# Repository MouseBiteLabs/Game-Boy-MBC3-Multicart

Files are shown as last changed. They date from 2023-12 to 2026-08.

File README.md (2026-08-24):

# Game Boy MBC3 Multicart

This is my design of a flashable MBC3-based multicart for the Game Boy. You can make a 2-in-1 or 4-in-1 cartridge, that changes games based on a button press or power cycling the Game Boy. With this board you can also make a single game, but with the addition of a pressable reset button on the cartridge.

The features are as follows:

- Able to make a cartridge with either 2x 2 MB games or 4x 1 MB games
- Adds a pressable button to the cartridge (no shell cutting required)
  - The button can be configured to cycle games on the cart, reset the console, or both
- Configurable to have separate save data for each game, or to share the same save data across multiple games
- Fully compatible with the <a href="https://www.gbxcart.com/">GBxCart RW</a> so you can transfer games and save files to and from the board

Some examples of fun cartridges you can make with this board are:
- A single Pokemon game that has a reset button
- Both Pokemon Gold and Silver with separate saves
- Both Pokemon Gold and Silver with *the same* save (save files are compatible between versions!)
- Both Pokemon Gold and Silver with *the same* save that can switch between versions *during gameplay without resetting* (hotswap!)
- A single copy of Mary-Kate and Ashley - Pocket Planner with two separate save files

assemblepic

boardscan

All gerbers and source files can be found in this repo, as this project is fully open source. Technical documentation of the board can be found in the Technical folder.

## Tutorial Video

Here's a video companion to this repository, but you will still need to read the repo to complete the build.

Multicart Video Tutorial (http://www.youtube.com/watch?v=DJ7rJUZhDuM "Game Boy Multicart Tutorial (Pokemon Gold and Silver)")

## Important Things Before You Start

The most important thing to note is that SW2A MUST be in the OFF position. The board is still fully functional as long as you rely on the button inside the cartridge to switch games. **You cannot cycle games by turning the power on and off.** Details are below.

1) To use this board, you need to have an original Game Boy game that uses an MBC3 mapper chip. <a href="https://catskull.net/gb-rom-database/">You can find a list of games and their mappers here</a>. Use the search function. Please note the RAM is in bytes, not bits. Since SRAM in this repo is defined in bits, you need to convert by multiplying the number of bytes by 8.
2) You will need to remove the MBC3 from your donor cartridge for use on this board. This will require a hot air rework station or a hot plate. There's a list below of other parts you can re-use from the donor cartridge.
3) When soldering parts on, it's a good idea to put kapton tape or otherwise cover the bottom cartridge edge. You do not want to get solder on the cartridge contacts.
4) I am not responsible for any damage you do to your self or your property. Attempt this project at your own risk.
5) I do not guarantee design compatibility. You may encounter issues with certain games. There is also a chance I have made an error in the design or the BOM - if this is the case, I will do everything I can to address the problem as quickly as possible.
6) If you are using this board to make games other than for personal use, you must have permission from the originator to use and distribute any ROM images or other related material. You are responsible for making sure you adhere to any license requirements.

DO NOT use my circuit boards for profiting from stolen work - this especially includes homebrew content, ROM hacks, and using fan-made labels without permission from the originator. **Support original creators!**

## Board Characteristics and Order Information

The zipped folder contains all the gerber files for this board. The following options **must** be chosen when ordering boards for yourself.

- Thickness: 0.8mm
- Surface Finish: ENIG
- Gold Fingers: Yes, 30° chamfer

**Add this note to orders:** "The milling.gbr layer indicates where an unplated slot should be added to the board. Please add an unplated slot as indicated."

You can use the zipped folder at any board fabricator you like. You may also buy the board from PCBWay using this link (disclosure: I receive 10% of the sale value to go twoards future PCB orders of my own):

<a href="https://www.pcbway.com/project/shareproject/Game_Boy_MBC3_Multicart_9962e82f.html">PCB from PCBWay</a>

<a href="https://oshpark.com/shared_projects/9DCMXwOu">The board is also listed on OSH Park as well.</a> **Be sure to get them in 0.8mm thickness if you order from here.**

### Purchase from My Website

You can purchase this circuit board at my website, [https://mousebitelabs.store](https://mousebitelabs.store). Click the following image to be directed to the specific item listing:

<a href="https://mousebitelabs.store/products/game-boy-mbc3-multicart-circuit-board">PCB from MouseBiteLabs</a>

### Purchase from Etsy

I also offer the board on Etsy, if you would rather purchase through there - click the banner to be redirected.

<a href="https://mousebitelabs.etsy.com/listing/1651715531">PCB from Etsy</a> 

## Required Equipment

The EEPROMs on the board needs to be programmed somehow. I recommend using the GBxCart, as mentioned. These boards are fully compatible with it, and it makes reflashing games extremely easy using <a href="https://github.com/lesserkuma/FlashGBX">lesserkuma's FlashGBX software</a>.

Alternatively, you can buy an EEPROM programmer with a TSOP adapter. The downside to this method is that you have to desolder the chip every time you want to program it. The <a href="https://flashcatusb.com/">FlashcatUSB</a> is one popular option in retro spaces.

## Battery Safety

When assembling a board, I recommend populating all the parts *except* the battery, and getting it to run initially without it. This is to make it easier to fix any solder connections that might need fixing, without having to worry about getting the battery hot. And if you need to rework anything near the battery after you've put it on the board, be safe and remove it before putting a hot soldering iron next to it.

And this should go without saying, but if you're assembling these boards with a hot plate or hot air, *do not* solder the battery on this way. You should use an iron, and keep heat off of the battery as much as possible. 

(Also check polarity!)

## Board Configurations

There's a lot to cover here. There are four separate switches to configure, and two different sizes of SRAM to pick from. You also can add a real-time clock to the cartridge for games that needed it.

*Note that you can simply solder bridges from the middle pads of the switches to the left or right to the "ON" or "OFF" positions, instead of installing an actual switch.*

### Real-Time Clock (RTC)

If your game uses an RTC, populate C2, R2, X1, and Z1 as indicated in the BOM.

If your game does *not* use the RTC function, you can omit these parts, but you also need to bridge the pads of Z1 with solder.



### SRAM Size Selection

There are two sizes of SRAM you can use, and the type you use will dictate how your save data is stored on the cartridge and if it's shared between games or not.

- If you use a 1 Mbit SRAM (like the AS6C1008), then each game you put on the cartridge will have its own separate save files. If you program multiple copies of the same game, then you can effectively have multiple save files on the same cart. Easy example is Pokemon games - they only let you have one save file, but if you put Pokemon Red on the multicart four times, then that gives you four separate save files!
- If you use a 256 Kbit SRAM (like the AS6C62256) then all the games you put on the cartridge will *share* the same RAM space.  This feature is probably only useful for Pokemon games. As an example: this means that if you made a cart that has Pokemon Red and Blue on it, you would play both versions with the same save data, as save data between the two games are compatible with each other.

### Game Cycling Mode Switch (SW2)

SW2, split into two separate switches SW2A (bottom half) and SW2B (top half), controls how you change games/save data on the cartridge. The following table describes the different settings:

**DUE TO AN OVERLOOKED DATASHEET ERROR, SW2A *MUST* BE TURNED OFF. DO NOT USE IT IN THE "ON" POSITION.**

| Mode | SW2A (Bottom) | SW2B (Top) | Game change with reset? | Game change with button press? | Does the button reset? |
| ---- | --- | --- | --- | --- | --- |
| 1 | OFF | OFF | No | Yes | Yes |
| 2 | OFF | ON | No | Yes | No |
|~~3~~ | ~~ON~~ | ~~OFF~~ | ~~Yes~~ | ~~Yes~~ | ~~Yes~~ |
|~~4~~ | ~~ON~~ | ~~ON~~ | ~~Yes~~ | ~~No~~ | ~~No~~ |

The "game change" method in this table describes how you advance down the "game" columns described in the table for SW3.

### Game and Save Data Configuration Switch (SW3)

SW3, split into two separate switches SW3A (bottom half) and SW3B (top half), controls the order in which the ROM banks (the games) and the RAM banks (the save data) cycle. This table assumes you are using a 1 Mbit SRAM chip. If you are using a 256 Kbit SRAM, then every entry in the "RAM Banks" column can be described as "1x 256 Kbit", and all the "Game" columns will share that single RAM bank.

Please note that SW3A and SW3B are *different* than the SW3A and SW3B on the MBC5 Multicart PCB.

| Mode | SW3A (Top) | SW3B (Bottom) | ROM Banks  | RAM Banks | Game 1 | Game 2 | Game 3 | Game 4 |
| ---- | ---- | ---- | --- | --- | --- | --- | --- | --- |
| A | OFF  | ON | 2x 2 MB | 4x 256 Kbit | ROM1, RAM1 | ROM1, RAM2 | ROM2, RAM3 | ROM2, RAM4 |
| B | OFF  | OFF  | 4x 1 MB | 4x 256 Kbit | ROM1, RAM1 | ROM2, RAM2 | ROM3, RAM3 | ROM4, RAM4 |
| C | ON | ON | 2x 2 MB | 2x 256 Kbit | ROM1, RAM1 | ROM2, RAM2 | | |
| D | ON | OFF  | 2x 1 MB | 2x 256 Kbit | ROM1, RAM1 | ROM2, RAM2 | | |

*Note: Mode D is useless. Just use Mode C instead.*

### Game Mode Examples

Here's a list of example cartridges you can make with these settings:
1) Pokemon Red, Blue, Yellow, and Green on one cartridge with separate save files that changes only via pressing the button, which also resets the game: **Mode 1B** with 1 Mbit SRAM
~~2) Pokemon Gold and Silver with separate save files that changes by pressing the button *or* cycling power on the Game Boy: **Mode 3C** with 1 Mbit SRAM~~
3) Pokemon Gold and Silver with the same save file that hotswaps when you press the button on the cartridge (changing games during gameplay): **Mode 2C** with 256 Kbit SRAM

## How to Program Games

When using the GBxCart to program multiple games to the cartridge, it's recommended to turn SW2A and SW2B to the OFF position. To change ROM/RAM banks to program, simply press the SW1 tactile button between programming steps. Using FlashGBX's "Refresh" button should show that the game information on the left of the screen changes after pressing the button.

If you're programming the flash chip separate from the board, you'll need to concatenate all the ROM files together into one large 4 MB file to program the chip with.

## Test Points and Final Checkout

On the back of the board are five test points. Here's where they are connected:

- TP1: SRAM supply voltage
- TP2: Battery voltage (after R1)
- TP3: Battery voltage (positive terminal of battery)
- TP4: Ground
- TP5: VCC input voltage

After you assemble your game, you should measure the current out of the battery. But first, you should program it with the GBxCart, or if you programmed the EEPROM separately, put it into a Game Boy and cycle power once. Then, flip the PCB upside down on a non-conductive surface (not your leg), and set your multimeter in DC millivolts (or volts). Put the positive probe on TP3 and the negative probe on TP2. If you used a 10kΩ for R1, as indicated in the BOM, you should read a voltage in the single or tens of millivolts for non-RTC games, or up to 60 mV for games using a real-time clock. If you have something much higher, especially voltages above 100mV, then you likely have an issue or short circuit on the board somewhere.

**Note: You need to power up the game at least once before battery currents will make sense - the battery management ICs can start up in an unknown state before applying main power to the board.**

To estimate battery life, see <a href="https://github.com/MouseBiteLabs/Game-Boy-MBC3-Cartridge/tree/main/Technical#estimating-battery-life">this section in the MBC3 Technical Design Document</a>, or for more in-depth analysis, <a href="https://hackaday.io/project/11864-tritiled/log/72554-determining-maximum-runtime-176-to-202-years-cr2032">this Hackaday post</a>.

### Current Draw Measurements and Battery Selection

The revision of MBC3 chip you are using will influence how much current draw you get, and thus how long your battery life will last. For the test set up, I am replacing the battery with a regulated DC power supply set for 3 VDC for consistency, on my regular MBC3 cart board with an MM1134 chip for U4, and brand new AS6C62256 SRAM.

These numbers are for reference only - to help you decide which MBC3 revision to use for your game, if you have a choice. These numbers are similar to a regular MBC3 cartridge, but the current required for retaining save data on the multicart will be slightly higher (about 0.2 uA) due to the extra components.

| Rev | P/N | Current draw (without RTC) | Battery Life Estimate (no RTC, CR2025) | Current draw (with RTC) | Battery Life Estimate (RTC, CR2025)  |
| ----- | --- | --- | --- | --- | --- |
| MBC3A | LR38536B | 0.4 uA | 47 years | 1.7 uA | 11 years |
| MBC3A | BU3632K  | 0.7 uA | 27 years | 1.7 uA | 11 years |
| MBC3A | P-2 | 0.7 uA | 27 years | 4.1 uA | 5 years |
| MBC3B | BU3634K  | 0.8 uA | 24 years | 1.7 uA | 11 years |
| MBC3B | P-2 | 0.6 uA | 31 years | 3.9 uA | 5 years |

Here is the same table, but with AS6C1008 SRAM instead of AS6C62256. It draws approximately 1 uA more than the AS6C62256.

| Rev | P/N | Current draw (without RTC) | Battery Life Estimate (no RTC, CR2025) | Current draw (with RTC) | Battery Life Estimate (RTC, CR2025)  |
| ----- | --- | --- | --- | --- | --- |
| MBC3A | LR38536B | 1.4 uA | 13 years | 2.7 uA | 7 years |
| MBC3A | BU3632K  | 1.7 uA | 11 years | 2.7 uA | 7 years |
| MBC3A | P-2 | 1.7 uA | 11 years | 5.1 uA | 4 years |
| MBC3B | BU3634K  | 1.8 uA | 10 years | 2.7 uA | 7 years |
| MBC3B | P-2 | 1.6 uA | 12 years | 4.9 uA | 4 years |

*If you have one of the revisions of MBC3 chips is missing from the table, please contact me!*

### Battery Size Considerations

The coin cells commonly used on Game Boy carts in order of increasing size are CR2016, CR2025, and CR2032. The CR2032 is the thickest, but yields the longest battery life.

Batteries that are as large as CR2032 will fit inside the shell, *however*, due to the thickness of the CR2032, using one makes it so the shell cannot be pressed down very easily. This makes the button inside the shell difficult to press reliably. For this reason, I recommend using the CR2025.

You should still be able to get 10+ years of battery life out of a CR2025 and a non-P-2 revision MBC3 chip. <a href="https://github.com/MouseBiteLabs/Game-Boy-MBC3-Cartridge/tree/main/Technical#estimating-battery-life">See this section in my main MBC3 repository for estimating battery life here.</a>

I haven't tested it, but I believe using battery holders instead of pre-tabbed batteries will similarly cause issues with trying to press the button in the middle of the cartridge.

### Why not FRAM?

This board is only suitable for using SRAM. One downside to SRAM, if you haven't figured it out yet, is that you need a battery to keep the SRAM powered on even when the game is turned off. So eventually the battery will die, and your save data is lost. Some people have used FRAM, or Ferroelectric RAM, to keep save data around even after the battery dies (specifically, the popular part that's used for FRAM carts is the FM18W08). But, using this FRAM chip has a handful of downsides, and the benefit of keeping save data after the battery dies *in my opinion* does not outweigh the cons, which are as follows:

1) Quality, new stock, 5V tolerant FRAM is expensive ($12+ per part).
2) Cheaper FRAM chips from eBay or Aliexpress are notoriously flaky (anecdotally, ~50% success rate).
3) FM18W08 maxes out at 256K (which is restrictive for multicarts).
4) FRAM memory access requires different chip select timing than SRAM, and the Game Boy expects SRAM, so it is not natively compatible with FRAM carts. The Gameboy Color specifically cannot (easily) be made to properly access FM18W08 chip. You *can* use an OR gate and add the CLK on the cart edge to try to achieve the necessary timing, but it only works (properly) for DMG/MGB/SGB, not the GBC. It usually *works* in practice for GBC, but it's technically a datasheet violation and can potentially cause issues in edge cases. <a href="https://github.com/Gekkio">(Thanks to gekkio for pointing this out!)</a>

Brand new SRAM chips are ~$3, and having the SRAM footprint also allows you to use SRAM from an original cart if desired. 

Note that this isn't to throw shade at any FRAM-based carts, but for me personally, it's more trouble than it's worth.

## Board Fitment

The shape of this board was originally meant to mimic original Game Boy circuit boards as closely as possible (v1.1 and earlier). Unfortunately, when placed in some aftermarket Game Boy cartridge shells (like those from Cloud Game Store), the circuit board has a lot of freedom to rotate around the main screw hole in the bottom-middle of the cartridge. This can cause misalignment when you put it in a Game Boy, which can cause a game to either not load properly (garbled Game Boy logo) or shut off the Game Boy because of a short circuit. This isn't *dangerous* or anything, just annoying.

In order to make the boards fit nicer in any kind of shell, for v1.4 I added extended tabs of circuit board material to the edges of the cartridges to keep it from rotating too much in shells, which was suggested to me by <a href="https://github.com/orangeglo">orangeglo</a>! (Thanks!)

If you're having trouble fitting the circuit board into a shell, because the tabs interfere with the cart edges, you can safely sand or trim them down as there is no copper within the tabs themselves. The only shell that appears to require any kind of trimming are Kitsch-Bent shells.

## Bill of Materials (BOM)

*Please note that there was an error in the published BOM before February 24, 2024. If you assembled your board before that date, I recommend you replace R5, R6, and C8 to their new values listed below.*

| Reference Designators | Value/Part Number | Package | Description | Source |
| --- | --- | --- | --- | --- |
| B1 | CR2025, CR2016, CR2032*| See note above | Backup Battery | [https://mou.sr/3PLccol](https://mou.sr/3PLccol) |
| C1 | 0.1uF | 0603 | Capacitor (MLCC) | [https://mou.sr/3ENc15O](https://mou.sr/3ENc15O) |
| C2 | 15 pF | 0603 | Capacitor (MLCC) | [https://mou.sr/3PPorjO](https://mou.sr/3PPorjO) |
| Z1 | 15 pF | 0603 | Capacitor (MLCC) | [https://mou.sr/3PPorjO](https://mou.sr/3PPorjO) |
| C4 | 0.1uF | 0603 | Capacitor (MLCC) | [https://mou.sr/3ENc15O](https://mou.sr/3ENc15O) |
| C5 | 0.1uF | 0603 | Capacitor (MLCC) | [https://mou.sr/3ENc15O](https://mou.sr/3ENc15O) |
| C6 | 10uF | 0603 | Capacitor (MLCC) | [https://mou.sr/3mZtSkF](https://mou.sr/3mZtSkF) |
| C7 | 0.1uF | 0603 | Capacitor (MLCC) | [https://mou.sr/3ENc15O](https://mou.sr/3ENc15O) |
| C8 | 0.01uF | 0603 | Capacitor (MLCC) | [https://mou.sr/3AsRwK1](https://mou.sr/3AsRwK1) |
| Q1 | 2N7002 | SOT-23 | N-Channel FET | [https://mou.sr/3rgfh6J](https://mou.sr/3rgfh6J) |
| R1 | 10k | 0603 | Resistor | [https://mou.sr/3riR7IH](https://mou.sr/3riR7IH) |
| R2 | 330k | 0603 | Resistor | [https://mou.sr/3PZ2pvj](https://mou.sr/3PZ2pvj) |
| R5 | 130k | 0603 | Resistor | [https://mou.sr/3MjXliy](https://mou.sr/3MjXliy) |
| R6 | 130k | 0603 | Resistor | [https://mou.sr/3MjXliy](https://mou.sr/3MjXliy) |
| R8 | 10k | 0603 | Resistor | [https://mou.sr/3riR7IH](https://mou.sr/3riR7IH) |
| R9 | 130k | 0603 | Resistor | [https://mou.sr/3MjXliy](https://mou.sr/3MjXliy) |
| R10 | 49.9k | 0603 | Resistor | [https://mou.sr/3Q3NRZO](https://mou.sr/3Q3NRZO) |
| SW1 | See note | 5.2 x 5.2mm | Tactile Switch | See Note |
| SW2 | CAS-D20TA | J Form Lead | Dual SPDT | [https://mou.sr/44YZNT5](https://mou.sr/44YZNT5) |
| SW3 | CAS-D20TA | J Form Lead | Dual SPDT | [https://mou.sr/44YZNT5](https://mou.sr/44YZNT5) |
| U1 | 29F032, 29F033 | TSOP-40 | Flash EEPROM | AliExpress or eBay |
| U2 | MBC3A or MBC3B | QFP-32 | MBC3 Mapper | Donor MBC3 Game Boy cartridge |
| U3 | AS6C62256, AS6C1008 | SOP-28, SOP-32 | SRAM | [https://mou.sr/3sFegFF](https://mou.sr/3sFegFF) |
| U4 | TPS3613 | MSOP-10 | Battery Management | [https://mou.sr/45Ir2kh](https://mou.sr/45Ir2kh) |
| U5 | SN74HCS74 | TSSOP-14 | Dual Flip Flop | [https://mou.sr/3QYGEuT](https://mou.sr/3QYGEuT) |
| U6 | SN74AHC1G126 | SC70 | Tri-State Buffer | [https://mou.sr/3T9Zdim](https://mou.sr/3T9Zdim) |
| U7 | SN74AHC1G126 | SC70 | Tri-State Buffer | [https://mou.sr/3T9Zdim](https://mou.sr/3T9Zdim) |
| U8 | SN74AHC1G126 | SC70 | Tri-State Buffer | [https://mou.sr/3T9Zdim](https://mou.sr/3T9Zdim) |
| X1 | 32.768 kHz | Radial | Crystal Oscillator | [https://mou.sr/3ZteKuy](https://mou.sr/3ZteKuy) |

### Note about SW1

If SW1 is long enough, it will sit inside the shell in a way that lets you press it by lightly pressing on the cartridge shell. This way, you can activate it without removing it from the console. You need to find a switch that has an extended stem on AliExpress, eBay, or Amazon (**if you find a compatible switch on Mouser or Digikey, please let me know**). The measurements will be 5.2 mm x 5.2 mm, with a height of 3.5 mm. Sometimes these parts are listed as "4 mm x 4 mm" or "5 mm x 5 mm" instead. Check the datasheet, if available, to see if it'll fit the footprint. They should have listing pictures similar to the ones seen here:



### Note about SW2, SW3

Instead of using the somewhat pricey switch designated for SW2 and SW3, you can instead just bridge the pads with solder from the middle pad to the pad in the direction you want to set the switch to. For example - in the below picture, SW3A and SW3B are both in the "ON" position in both cases. (Note that the white switches on the right image are switched to the right.)



**REMINDER: SW2A MUST BE IN THE OFF POSITION.**

### Note about MBC3 Revisions

If you have a choice, I recommend against using the original revision-less MBC3 mapper for this specific circuit board. You should use an MBC3A or MBC3B if possible. Save the revision-less MBC3 chips for regular MBC3 cartridges!



*[Images of MBC3 chips from <a href="https://gbhwdb.gekkio.fi/cartridges/mbc3.html">Game Boy Hardware Database</a>.]*

### Usable Donor Cartridge Parts

You can use a few parts from the donor cart on the new board to save some money. Note that you will generally get better reliability with new parts as opposed to old ones. For example: I have seen failed RAM chips from donors in the past.

1) **C2, R2, X1, Z1: RTC Components** - You can move over these parts if you're using the real-time clock function. Note that Z1 and C2 are designated as C2 and C3 on my board. They're the same value, so they're interchangeable.
2) **U2: MBC3A or MBC3B** - This one is required
3) **U3: SRAM** - You can use this part *only if* the sum of the RAM space for the games you're using is the same or less amount of RAM that the donor cartridge has. If you plan to have separate save data for every game, you'll probably need to buy an AS6C1008.

You could probably transfer over most of the 0.1uF capacitors but they're pretty cheap anyway, so I generally just recommend buying new resistors and capacitors.

## Things to Remember

- The 29F032 and 29F033 have been known to occasionally be defective upon arrival. They're either used, or new old stock, and usually only available from AliExpress.
- The footprint for the battery can fit a CR2032, CR2025, or CR2016 with solder tabs. The only difference is the mAh capacity (larger number = longer life). If you get Panasonic tabbed batteries, you may have to trim the battery tabs to make them fit on the footprint.
- Generally, ROM sizes are conveyed in terms of kilobytes and megabytes (KB, MB). RAM size is usually conveyed in terms of kilobits or megabits (Kbit, Mbit). You can convert Kbit and Mbit to KB and MB by dividing Kbit or Mbit by 8. For example, 256 Kbit = 32 KB.

## Labels

If you want a Bucket Mouse branded label for your cartridge, look no further than <a href="https://krizdingus.com/mousebitelabs/">krizdingus's designs</a>. Special thanks to Kris for designing these, they look awesome! (If you are going to order/print these, use the high-res images hosted on his website, and *keep the labels for personal or non-commercial use only.*)



## Why does SW2A need to be OFF?

SW2A in the ON position previously allowed the multicart to swap games whenever you power cycled the Game Boy. This was achieved by connecting the /RST line on the Game Boy to the CLK input on the flip-flop. The /RST line was held low when power was off by the RESET output of the TPS3613 battery management IC driving the gate of a FET.

The datasheet says this output is a push-pull output, and implies it will behave normally when power is off and the battery is being relied on for power. However, that is not the behavior I have later found to be true. Instead, if the voltage on the VDD pin is too low (like when the power is turned off), this RESET output floats. This causes the FET to not be asserted, and then allows the /RST line to float.

In Modes 3 or 4, where SW2A is in the ON position, /RST is connected to the flip-flop's CLK input. If /RST floats, then CLK floats, which can cause excess current draw from the flip-flop, draining the battery much faster than expected. Therefore, it is recommended to ONLY use a button to change games, and not to rely on power cycling.

A new board to replace this design with something more suitable will be completed in the future. In the meantime, *do not put SW2A in the ON position.*

## Revision History

### v1.3
- Fixed debounce circuit for push button
- Adjusted board edge tabs to better fit in shells

### v1.2
- Changed C3 to Z1
- Added nubs on the board edge to prevent the circuit board from rattling around in aftermarket cartridges

### v1.1
- Fix schematic errors
- Extended cart edge down by 0.25 mm for better fitment
- Added OSHW logo and "SUPPORT ORIGINAL CREATORS!"

### v1.0
- Prototype revision

## Resources and Acknowledgements

- <a href="http://www.devrs.com/gb/files/hardware.html">Jeff Frohwein's GameBoy Tech Page</a>
- <a href="https://gbhwdb.gekkio.fi/">Game Boy Hardware Database</a>
- <a href="https://catskull.net/gb-rom-database/">Nintendo Gameboy Game List</a>
- <a href="https://www.gbxcart.com/">insideGadgets discord server for GBxCart RW compatibility requirements</a>
- <a href="https://github.com/lesserkuma/FlashGBX">Lesserkuma's FlashGBX software</a>
- <a href="https://www.ti.com/lit/ds/symlink/tps3613-01.pdf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">TPS3613 Datasheet</a>
- Board outline modified from <a href="https://tinkerer.us/projects/homebrew-gameboy-cartridge.html">Dillon Nichols's Homebrew Gameboy Cartridge project</a>
- Thanks to <a href="https://github.com/orangeglo">orangeglo</a> for his suggestion of adding spacers around the board edge for better fitment in aftermarket cartridges
- Some components from <a href="https://github.com/adafruit/Adafruit-Eagle-Library">Adafruit's Eagle parts library</a>
- Some components from <a href="https://www.snapeda.com/">SnapMagic</a>
- Thank you to <a href="https://github.com/Gekkio">gekkio</a> for their deep Game Boy knowledge resources, and for collaboration in demystifying some of the design choices on Game Boy cartridges
- Thanks to the awesome members of the <a href="https://moddedgameboy.club/">Modded Gameboy Club</a> for their feedback and support during the entire project development

## License

<br />This work is licensed under a <a rel="license" href="http://creativecommons.org/licenses/by-sa/4.0/">Creative Commons Attribution-ShareAlike 4.0 International License</a>. You are able to copy and redistribute the material in any medium or format, as well as remix, transform, or build upon the material for any purpose (even commercial) - but you **must** give appropriate credit, provide a link to the license, and indicate if any changes were made.

©MouseBiteLabs 2023

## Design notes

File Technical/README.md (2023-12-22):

# Technical Design Document

This write-up will serve as an attempt of explaining how this cartridge functions. I'm not going to explain the majority of the cart, as you can find most of the explanation in <a href="https://github.com/MouseBiteLabs/Game-Boy-MBC3-Cartridge/tree/main/Technical">my MBC3 repo.</a> Therefore, this write-up will mostly focus on how the multicart portion works and the necessary components to safely implement it.

Please correct me on any information I may have gotten wrong.

## Schematic



## Multicart Basics

A byte is eight bits - corresponding to the eight digital pins D0 to D7. The address pins A0 to A21 determine how many bytes the EEPROM can hold in memory. There are 22 address pins on the 29F033, and they can be either 0 or 1 - therefore the EEPROM can hold 2^22, or 4,194,304, bytes total. Each byte is located at a different "address". Note that the ROM chip 29F033 is a 4 MB EEPROM - see where the 4 comes from? So, this should mean we can hold one 4 MB ROM file on the chip. But, we could also store two 2 MB ROMs, or four 1 MB ROMs, because those add up to 4 MB.

If we want to hold 2 MB of data we only need 21 address pins, A0 through A20, because 2^21 is 2,097,152 - half of the total bytes with 22 address pins. **So omitting one address pin halves the amount of bytes the EEPROM can hold.** But we still have that extra address pin A21; the total space of the chip is *still* 4 MB. If we set A21 at 0 while programming the first game using address pins A0 through A20, then we can set it to 1 to use the rest of the available space on the chip for a second game. Then we simply toggle the A21 pin to 0 or 1 to switch games. These are typically referred to as "memory banks".



If we wanted to do four games, we just take the next highest address pin, A20, and toggle that between 0 and 1 as well. Then you have two address pins that can be either 0 or 1, giving you four combinations, and thus four banks of memory.

## D Flip-Flop

A flip-flop is a basic electronic device that can store memory. The output Q will be set to the input D whenever the clock pin is pulsed (normally on the rising edge of the clock signal). If the D pin changes value at all, the output of Q (and /Q, which is the inverse of Q) will not be affected, until the clock signal rises again. The output therefore only updates to whatever is seen on the input when the clock signal rises from low to high.



The /PRE and /CLR pins are used for setting the Q and /Q outputs to a specific value, ignoring the D input and clock pin. If you set them both high, then the flip-flop can operate normally.

So if we connect the D input to the /Q output, then we can essentially make a clock divider circuit. See the timing diagram below:



When the clock pin rises, the data from the D pin is loaded onto the Q output. Because D is connected to /Q, Q will become whatever /Q was when the clock rises. And thus, /Q will become the opposite of Q. As you can see, this effectively divides the clock frequency in half, switching between 1 and 0 every time the clock pulses.

Now, we can connect the clock pin to a button, with a pull-up resistor to VCC. Whenever we press the button, it shorts the clock pin to GND, and when we release, that gives the clock pin a rising edge as the pull-up resistor pulls the voltage back to VCC. So with every button press, the output of the flip-flop toggles from 0 to 1 or from 1 to 0. Connect that output pin to the upper address pin on the EEPROM, and you now have a way to switch between the two ROMs with a button. Or, if you connect the clock pin to the /RESET pin 30 on the cart edge, which goes low when power is turned off, you now will switch ROMs every time the /RESET pin rises as the game is turned on.

### Two D Flip-Flops

But why stop there? What if we add another flip-flop with the D and /Q pins tied together, but instead connect the output Q of the first flip-flop to the clock input of the second flip-flop?



Now we get *another* clock divider. The output Q2 is now half the frequency of Q1. We have just made a binary counter - every button press counts up on the output pins - 00, 01, 10, 11, then back to 00. If we take this *second* output and connect it to our second highest address pin, we can now switch bewteen four separate ROM files.

*The same outputs can be connected to the RAM address pins for the same end effect, so you have separate RAM banks to match the ROM banks.*

### Schmitt Trigger

What's that funky symbol next to the /PRE, CLK, /CLR, and D pins? This indicates these input pins have a Schmitt trigger. Using a Schmitt trigger is a way of cleaning up an input signal, kind of like debouncing. If your input is noisy, or slow, a Schmitt trigger will prevent the input signal from flipping the logic  between 0 and 1 rapidly. It's best seen in this table from the SN74HCS74 datasheet (you can ignore the "Low Power" column for our purposes).



What's really beneficial here is the "Supports Slow Inputs" column. The /RESET signal (cart edge pin 30) is *very* slow, relative to what logic chips are usually expecting. The rise time is in the milliseconds; on discrete logic chips without Schmitt trigger inputs, the changes are measured in *nano*seconds. If you have a signal too slow, it can cause the bouncing seen in the Chaotic Neutral square. So for the purposes of a /RESET or button triggered multicart, the Schmitt trigger is a *must*.

### Preserving Game Selection

In order to keep the state of the flip-flop persistent across resets/power cycles, so it "remembers" which game you were playing before toggling the clock pin, it must be operational on battery power via the battery management IC, TPS3613. This is somewhat unfortunate - the more devices you run on battery power, the shorter battery life will become. Luckily, the SN74HCS74 has a typical supply current requirement of 0.1 uA (max of 2 uA). The MBC3 itself will probably suck up more power than this!

## Tri-State Buffers

U6, U7, and U8 are what's known as tri-state buffers. The output pin Y will be whatever the input pin A is, as long as the OE pin is pulled HIGH. When the OE pin is LOW, then the output of Y is high impedance, or "floating" - not HIGH *or* LOW. U6's and U7's OE pins are connected to /RESGATE, which is HIGH whenever power is supplied to the cartridge from the Game Boy (i.e. when the game is not running on battery power) and LOW whenever the Game Boy is off. U8's OE pin is tied directly to VCC, the cartridge input voltage.

The reason the U6 and U7 buffers are important is the EEPROM is powered by VCC, and *not* by the battery. If we connected the outputs of the flip-flops directly to the address pins, because the dual flip-flop is powered on battery, the states of the address pins could feasibly be at 3 V. The EEPROM's datasheet specifies the voltage on the input pins be no larger than 0.5 V above VCC. Since the VCC pin will be 0 V, we'd be violating the datasheet requirements and potentially damaging the chip.

The buffers that have been chosen *can* handle a voltage on their input pins if VCC is 0 V. There is a small leakage current through the input pins if either or both of the flip-flop outputs are high, however it's only 0.1 uA *max* at ambient temperature, so again a negligible impact.

The reason U8 is important is if it's not included and the /MR pin of U4 is connected directly to the button, then the RC circuit on the button would discharge the battery through the /MR pin, which is internally pulled up to VCC.

## TPS3613 Master Reset Pin

The TPS3613 is already explained in more detail in the MBC3 technical design document, but one minor difference in implementation here is that the master reset pin (/MR) is connected to SW1 (through U8) when SW2A is set to the OFF position. As mentioned, /MR is pulled up internally in the TPS3613 - and when it's grounded with a press of SW1, the /RESET output is pulled low and the positive RESET output is pulled high. This will reset the MBC3 and the Game Boy via the cart edge /RST pin 30, until you release the button. 

## Resources

- <a href="http://www.devrs.com/gb/files/hardware.html">Jeff Frohwein's GameBoy Tech Page</a>
- <a href="https://gbhwdb.gekkio.fi/">Game Boy Hardware Database</a>
- <a href="https://catskull.net/gb-rom-database/">Nintendo Gameboy Game List</a>
- <a href="https://www.ti.com/lit/ds/symlink/tps3613-01.pdf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">TPS3613 Datasheet</a>
- <a href="https://www.ti.com/lit/ds/symlink/sn74hcs74-q1.pdf">SN74HCS74 Datasheet</a>
- <a href="https://www.ti.com/lit/ds/symlink/sn74ahc1g08.pdf">SN74AHC1G08 Datasheet</a>
- <a href="https://github.com/Gekkio/gb-schematics/blob/main/DMG-CPU-06/schematic/DMG-CPU-06.pdf">Gekkio's Game Boy Schematic Resources</a>

## License
<br />This work is licensed under a <a rel="license" href="http://creativecommons.org/licenses/by-sa/4.0/">Creative Commons Attribution-ShareAlike 4.0 International License</a>. You are able to copy and redistribute the material in any medium or format, as well as remix, transform, or build upon the material for any purpose (even commercial) - but you **must** give appropriate credit, provide a link to the license, and indicate if any changes were made.

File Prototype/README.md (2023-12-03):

# Prototype Board Information

Only follow this if you have a v1.0 or v1.1 board!!

## Fix to v1.0

- Lift pin 31 on the SRAM if you're using a 1 Mbit SRAM (AS6C1008) so that it does not connect to the circuit board. Wire this lifted pin to pin 4 of U6.
- For SW2A (the top switch), if you want it to be in the "ON" position, you must manually wire the middle pad to pin 4 and 5 of U4 - this means you have to remove the switch. You'll need to manually solder the SW2B as well if the switch is removed.

## Board Configurations

There are four separate switches to configure, and two different sizes of SRAM to pick from. You also can add a real-time clock to the cartridge for games that needed it.

*Note that you can simply solder bridges from the middle pads of the switches to the left or right to the "ON" or "OFF" positions, instead of installing an actual switch.*

### Real-Time Clock (RTC)

If your game uses an RTC, populate C2, C3, R2, and X1 as indicated in the BOM.

If your game does *not* use the RTC function, you can omit these parts. But you need to bridge the pads of C3.



### SRAM Size Selection

There are two sizes of SRAM you can use, and the type you use will dictate how your save data is stored on the cartridge and if it's shared between games or not.

- If you use a 1 Mbit SRAM (like the AS6C1008), then each game you put on the cartridge will have its own separate save files. If you program multiple copies of the same game, then you can effectively have multiple save files on the same cart. Easy example is Pokemon games - they only let you have one save file, but if you put Pokemon Red on the multicart four times, then that gives you four separate save files!
- If you use a 256 Kbit SRAM (like the AS6C62256) then all the games you put on the cartridge will *share* the same RAM space.  This feature is probably only useful for Pokemon games. As an example: this means that if you made a cart that has Pokemon Red and Blue on it, you would play both versions with the same save data, as save data between the two games are compatible with each other.

### Game Cycling Mode Switch (SW2)

SW2, split into two separate switches SW2A (top half) and SW2B (bottom half), controls how you change games on the cartridge. The following table describes the different settings:

| Mode | SW2A (Top) | SW2B (Bottom) | Game Change Method | Resets the Console? |
| ---- | --- | --- | --- | --- |
| 1 | OFF | ON | Cycle power | Yes |
| 2 | ON | ON | Press button | Yes |
| 3 | OFF | OFF | Press button | No |
| 4 | ON | OFF | No change | Yes |

*Note: Mode 4 will effectively act as a single-game cartridge with an added reset button. This mode does not require populating SW1, U5, and U7. But it requires you to place SW3 into mode C, and restricts your game size to 2 MB and RAM size to 256 Kbit.*

### Game and Save Data Configuration Switch (SW3)

SW3, split into two separate switches SW3A (bottom half) and SW3B (top half), controls the order in which the ROM banks (the games) and the RAM banks (the save data) cycle. This table assumes you are using a 1 Mbit SRAM chip, as a 256 Kbit SRAM will share save data across all ROMs.

| Mode | SW3A | SW3B | ROM Banks  | RAM Banks | Game 1 | Game 2 | Game 3 | Game 4 |
| ---- | ---- | ---- | --- | --- | --- | --- | --- | --- |
| A | ON | OFF  | 2x 2 MB | 4x 256 Kbit | ROM1, RAM1 | ROM1, RAM2 | ROM2, RAM3 | ROM2, RAM4 |
| B | OFF  | OFF  | 4x 1 MB | 4x 256 Kbit | ROM1, RAM1 | ROM2, RAM2 | ROM3, RAM3 | ROM4, RAM4 |
| C | ON | ON | 2x 2 MB | 2x 256 Kbit | ROM1, RAM1 | ROM2, RAM2 | | |
| D | OFF  | ON | 2x 1 MB | 2x 256 Kbit | ROM1, RAM1 | ROM2, RAM2 | | |

*Note: Mode D is useless. Just use Mode C instead.*

### Game Mode Examples

Here's a list of example cartridges you can make with these settings:
1) Pokemon Red, Blue, Yellow, and Green on one cartridge with separate save files that changes via powering the Game Boy off and on again: **Mode 1B** with 1 Mbit SRAM
2) Pokemon Gold and Silver with the same save file that hotswaps when you press the button on the cartridge (changing games during gameplay): **Mode 3C** with 256 Kbit SRAM
3) Pokemon Crystal with a reset button: **Mode 4C** with 256 Kbit SRAM

## How to Program Games

When using the GBxCart to program multiple games to the cartridge, it's recommended to turn SW2A and SW2B to the OFF position. To change ROM/RAM banks to program, simply press the SW1 tactile button between programming steps. Using FlashGBX's "Refresh" button should show that the game information on the left of the screen changes after pressing the button.

If you're programming the flash chip separate from the board, you'll need to concatenate all the ROM files together into one large 4 MB file to program the chip with.

## Test Points and Final Checkout

On the back of the board are five test points. Here's where they are connected:

- TP1: SRAM supply voltage
- TP2: Battery voltage (after R1)
- TP3: Battery voltage (positive terminal of battery)
- TP4: Ground
- TP5: VCC input voltage

After you assemble your game, you should measure the current out of the battery. But first, you should program it with the GBxCart, or if you programmed the EEPROM separately, put it into a Game Boy and cycle power once. Then, flip the PCB upside down on a non-conductive surface (not your leg), and set your multimeter in DC millivolts (or volts). Put the positive probe on TP3 and the negative probe on TP2. If you used a 10kΩ for R1, as indicated in the BOM, you should read a voltage in the single or tens of millivolts for non-RTC games, or up to 60 mV for games using a real-time clock. If you have something much higher, especially voltages above 60mV, then you likely have an issue or short circuit on the board somewhere.

## Bill of Materials (BOM)

Do not populate R7 or C11.

| Reference Designators | Value/Part Number | Package | Description | Source |
| --- | --- | --- | --- | --- |
| B1 | CR2032, CR2025, CR2016 | CR2032 | Backup Battery | [https://mou.sr/3SeAzfT](https://mou.sr/3SeAzfT) |
| C1 | 0.1uF | 0603 | Capacitor (MLCC) | [https://mou.sr/3ENc15O](https://mou.sr/3ENc15O) |
| C2 | 15 pF | 0603 | Capacitor (MLCC) | [https://mou.sr/3PPorjO](https://mou.sr/3PPorjO) |
| C3 | 15 pF | 0603 | Capacitor (MLCC) | [https://mou.sr/3PPorjO](https://mou.sr/3PPorjO) |
| C4 | 0.1uF | 0603 | Capacitor (MLCC) | [https://mou.sr/3ENc15O](https://mou.sr/3ENc15O) |
| C5 | 0.1uF | 0603 | Capacitor (MLCC) | [https://mou.sr/3ENc15O](https://mou.sr/3ENc15O) |
| C6 | 10uF | 0603 | Capacitor (MLCC) | [https://mou.sr/3mZtSkF](https://mou.sr/3mZtSkF) |
| C7 | 0.1uF | 0603 | Capacitor (MLCC) | [https://mou.sr/3ENc15O](https://mou.sr/3ENc15O) |
| C8 | 0.1uF | 0603 | Capacitor (MLCC) | [https://mou.sr/3ENc15O](https://mou.sr/3ENc15O) |
| Q1 | 2N7002 | SOT-23 | N-Channel FET | [https://mou.sr/3rgfh6J](https://mou.sr/3rgfh6J) |
| R1 | 10k | 0603 | Resistor | [https://mou.sr/3riR7IH](https://mou.sr/3riR7IH) |
| R2 | 330k | 0603 | Resistor | [https://mou.sr/3PZ2pvj](https://mou.sr/3PZ2pvj) |
| R5 | 10k | 0603 | Resistor | [https://mou.sr/3riR7IH](https://mou.sr/3riR7IH) |
| R8 | 10k | 0603 | Resistor | [https://mou.sr/3riR7IH](https://mou.sr/3riR7IH) |
| R9 | 130k | 0603 | Resistor | [https://mou.sr/3MjXliy](https://mou.sr/3MjXliy) |
| R6 or R10 | 49.9k | 0603 | Resistor | [https://mou.sr/3Q3NRZO](https://mou.sr/3Q3NRZO) |
| SW1 | See note | 5.2 x 5.2mm | Tactile Switch | [https://mou.sr/3uipCQz](https://mou.sr/3uipCQz) OR see note |
| SW2 | CAS-D20TA | J Form Lead | Dual SPDT | [https://mou.sr/46gGqF1](https://mou.sr/46gGqF1) |
| SW3 | CAS-D20TA | J Form Lead | Dual SPDT | [https://mou.sr/46gGqF1](https://mou.sr/46gGqF1) |
| U1 | 29F032, 29F033 | TSOP-40 | Flash EEPROM | AliExpress or eBay |
| U2 | MBC3A or MBC3B | QFP-32 | MBC3 Mapper | Donor MBC3 Game Boy cartridge |
| U3 | AS6C62256, AS6C1008 | SOP-28, SOP-32 | SRAM | [https://mou.sr/3sFegFF](https://mou.sr/3sFegFF) |
| U4 | TPS3613 | MSOP-10 | Battery Management | [https://mou.sr/45Ir2kh](https://mou.sr/45Ir2kh) |
| U5 | SN74HCS74 | TSSOP-14 | Dual Flip Flop | [https://mou.sr/3QYGEuT](https://mou.sr/3QYGEuT) |
| U6 | SN74AHC1G08 | SOT-23-5 | 2-input AND Gate | [https://mou.sr/3Bku2qj](https://mou.sr/3Bku2qj) |
| U7 | SN74AHC1G08 | SOT-23-5 | 2-input AND Gate | [https://mou.sr/3Bku2qj](https://mou.sr/3Bku2qj) |
| X1 | 32.768 kHz | Radial | Crystal Oscillator | [https://mou.sr/3ZteKuy](https://mou.sr/3ZteKuy) |

### Note about SW1

SW1 can be either short or long. If the button is long enough, it will sit inside the shell in a way that lets you press it by lightly pressing on the cartridge shell. This way, you can activate it without removing it from the console. This is helpful if you want to change games via a button press.

- If you want to make the button pressable when the cartridge is fully assembled, you need to find a switch that has an extended stem on AliExpress, eBay, or Amazon (**if you find a compatible switch on Mouser or Digikey, please let me know**). The measurements will be 5.2 mm x 5.2 mm, with a height of 3.5 mm. Sometimes these parts are listed as "4 mm x 4 mm" or "5 mm x 5 mm" instead. Check the datasheet, if available, to see if it'll fit the footprint. They should have listing pictures similar to the ones seen here:



- If you don't care about pressing the button while it's in the shell, like if you are making a multicart that changes games by cycling the power where you wouldn't need it, then you can simply use the TS18-5-25-SL-260-SMT-TR (https://mou.sr/3uipCQz).

### Note about MBC3 Revisions

If you have a choice, I recommend against using the original revision-less MBC3 mapper for this specific circuit board. You should use an MBC3A or MBC3B if possible. Save the revision-less MBC3 chips for regular MBC3 cartridges!



*[Images of MBC3 chips from <a href="https://gbhwdb.gekkio.fi/cartridges/mbc3.html">Game Boy Hardware Database</a>.]*

### Usable Donor Cartridge Parts

You can use a few parts from the donor cart on the new board to save some money. Note that you will generally get better reliability with new parts as opposed to old ones. For example: I have seen failed RAM chips from donors in the past.

1) **C1, C2, R2, X1: RTC Components** - You can move over these parts if you're using the real-time clock function. Note that C1 and C2 are designated as C2 and C3 on my board. They're the same value, so they're interchangeable.
2) **U2: MBC3A or MBC3B** - This one is required
3) **U3: SRAM** - You can use this part *only if* the sum of the RAM space for the games you're using is the same or less amount of RAM that the donor cartridge has. If you plan to have separate save data for every game, you'll probably need to buy an AS6C1008.

You could probably transfer over most of the 0.1uF capacitors but they're pretty cheap anyway, so I generally just recommend buying new resistors and capacitors.

## Things to Remember

- The 29F032 and 29F033 have been known to occasionally be defective upon arrival. They're either used, or new old stock, and usually only available from AliExpress.
- The footprint for the battery can fit a CR2032, CR2025, or CR2016 with solder tabs. The only difference is the mAh capacity (larger number = longer life). If you get Panasonic tabbed batteries, you may have to trim the battery tabs to make them fit on the footprint.
  - For untabbed coin cells, you can find battery retainer adapters online, <a href="https://retrogamerepairshop.com/products/hdr-game-boy-game-battery-retainer?variant=40511013290156">like this one.</a>
- Generally, ROM sizes are conveyed in terms of kilobytes (KB) and megabytes (KB, MB). RAM size is usually conveyed in terms of kilobits or megabits (Kbit, Mbit). You can convert Kbit and Mbit to KB and MB by dividing Kbit or Mbit by 8. For example, 256 Kbit = 32 KB.

## License

<br />This work is licensed under a <a rel="license" href="http://creativecommons.org/licenses/by-sa/4.0/">Creative Commons Attribution-ShareAlike 4.0 International License</a>. You are able to copy and redistribute the material in any medium or format, as well as remix, transform, or build upon the material for any purpose (even commercial) - but you **must** give appropriate credit, provide a link to the license, and indicate if any changes were made.

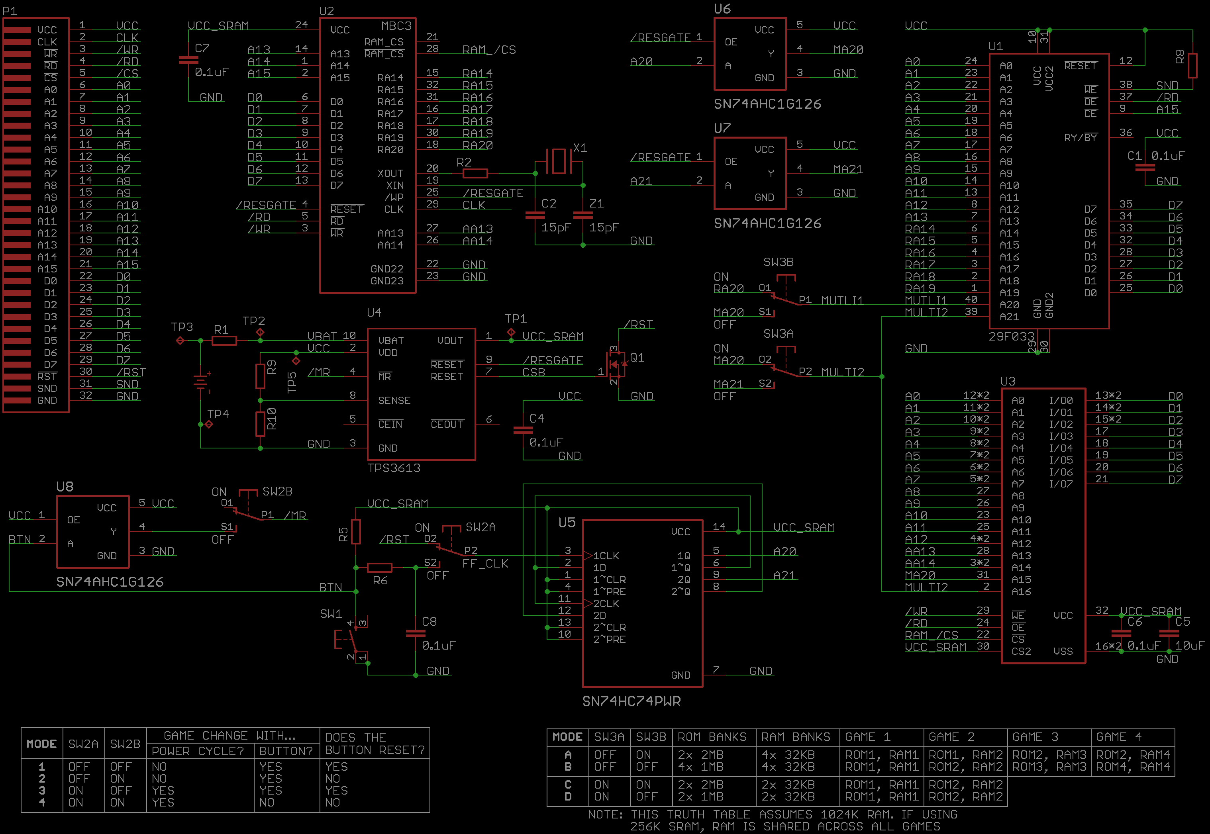
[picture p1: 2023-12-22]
Technical/schematic.png

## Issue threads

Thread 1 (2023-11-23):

why not use fram？

hualazimo7, 2023-11-23:
why not replace the sram by fram？like fm18w08？

MouseBiteLabs, 2023-11-23:
I should add a section for this question.

1) Good new FRAM is expensive ($12+). Cheap FRAM from aliexpress is flaky
(anecdotally, ~50% success rate)
2) SRAM footprint allows you to use SRAM from an original cart.
3) FM18W08 maxes out at only 256K.
4) The Gameboy Color specifically cannot (easily) be made to properly
access the FRAM chip (FM18W08 anyway). FRAM memory access requires
different chip select timing than SRAM, and the Game Boy expects SRAM, so
it is not natively compatible with FRAM carts. You can use an OR gate and
add the CLK on the cart edge to make this timing work, but it only works
(properly) for DMG/MGB/SGB, not the GBC. It usually works in practice for
GBC, but it's technically a datasheet violation and can potentially cause
issues in edge cases. (Thanks to gekkio for pointing this out)

There are proper FRAM chips you can use that work similar to SRAM, but
they're even more expensive and have a completely different footprint.

SRAM + battery lasts for over a decade (even longer if you're not using an
RTC), costs less, and is much more reliable than FRAM. This isn't to throw
shade at any FRAM-based carts, but for me it's more trouble than it's worth.

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

hualazimo7, 2023-11-24:
Just a week ago ,  i assembled a pokemon cart using the pcb designed by _'_HDR_‘’_ . With FRAM 'fm18w08-SG' from aliexpress, my pokemon sliver ‘s  save file will be broken  certainly  when i used the cart on different cnsoles. For example, from gbasp  to  gbc.
It could be the question you just answered.
Maybe i should buy more FRAMS to test or just use your pcb.
Thanks for reply ,thanks for your work.😊

hualazimo7, 2023-11-24:
Just a week ago ,  i assembled a pokemon cart using the pcb designed by _'_HDR_‘’_ . With FRAM 'fm18w08-SG' from aliexpress, my pokemon sliver ‘s  save file will be broken  certainly  when i used the cart on different cnsoles. For example, from gbasp  to  gbc.
It could be the question you just answered.
Maybe i should buy more FRAMS to test or just use your pcb.
Thanks for reply ,thanks for your work.😊

> I should add a section for this question. 1) Good new FRAM is expensive ($12+). Cheap FRAM from aliexpress is flaky (anecdotally, ~50% success rate) 2) SRAM footprint allows you to use SRAM from an original cart. 3) FM18W08 maxes out at only 256K. 4) The Gameboy Color specifically cannot (easily) be made to properly access the FRAM chip (FM18W08 anyway). FRAM memory access requires different chip select timing than SRAM, and the Game Boy expects SRAM, so it is not natively compatible with FRAM carts. You can use an OR gate and add the CLK on the cart edge to make this timing work, but it only works (properly) for DMG/MGB/SGB, not the GBC. It usually works in practice for GBC, but it's technically a datasheet violation and can potentially cause issues in edge cases. (Thanks to gekkio for pointing this out) There are proper FRAM chips you can use that work similar to SRAM, but they're even more expensive and have a completely different footprint. SRAM + battery lasts for over a decade (even longer if you're not using an RTC), costs less, and is much more reliable than FRAM. This isn't to throw shade at any FRAM-based carts, but for me it's more trouble than it's worth.
> […](#)
> On Thu, Nov 23, 2023, 9:53 AM hualazimo7 ***@***.***> wrote: why not replace the sram by fram？like fm18w08？ — Reply to this email directly, view it on GitHub <#1>, or unsubscribe <https://githubfast.com/notifications/unsubscribe-auth/AXFAY4YMQYQ4B3L7KO6JPVTYF5PO3AVCNFSM6AAAAAA7X4TZJOVHI2DSMVQWIX3LMV43ASLTON2WKOZSGAYDQMZYGIZDGNA> . You are receiving this because you are subscribed to this thread.Message ID: ***@***.***>

hualazimo7, 2023-11-24:
Just a week ago ,  i assembled a pokemon cart using the pcb designed by _'_HDR_‘’_ . With FRAM 'fm18w08-SG' from aliexpress, my pokemon sliver ‘s  save file will be broken  certainly  when i used the cart on different cnsoles. For example, from gbasp  to  gbc.
It could be the question you just answered.
Maybe i should buy more FRAMS to test or just use your pcb.
Thanks for reply ,thanks for your work.😊

Closed 2024-07-09.

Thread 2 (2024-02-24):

Pressing the button (SW1) drops SRAM voltage too low [FIXED!]

MouseBiteLabs, 2024-02-24:
There's an error in the BOM for the MBC3 and MBC5 multicarts (before February 24, 2024). If you built it with R5 and R6 as 10kΩ resistors and C8 as a 0.1uF capacitor, then when you press the button (SW1) while the Game Boy is powered OFF, the voltage on the SRAM supply will drop to 1/2 of the battery voltage as long as you have the button pressed (~1.5V). Thus, the following issues *may* occur if you press the multicart button to change games while the Game Boy is powered OFF only:

- Cartridge may randomly pick one of the games at start-up (last played game is not preserved)
- **Save data may be lost if battery voltage is low enough (but higher than expected for loss of data)**

This is more likely to happen if you are using old, harvested SRAM as compared to the new Alliance parts I specify in the BOM. The reason for this is because the Alliance SRAM's data retention voltage is specified as 1.5V, whereas some of the older SRAM chips that I've checked have this voltage as 2V.

These issues are currently theoretical, and I can't actually get them to happen myself, unless I presumably use a low voltage save battery or specific models of older SRAM. The practical implication of this error is that your save data might be lost earlier than expected, only if you change games when the Game Boy is turned off. If you have the Game Boy on and press the button, the issues will not occur. Luckily, changing the parts is easy, as they're pretty easily accessible. You can do one of the following:

**Fix No. 1 (preferred):**
- Change R5 and R6 to 130kΩ: https://mou.sr/3MjXliy
- Change C8 to 0.01uF: https://mou.sr/3AsRwK1
The 130kΩ resistor is the same one used for R9. You may have extras.
The cap is the same used on the MGBC/DMGC projects, if you've done those you likely have some extras. If you haven't, pretty much any 0.01uF will work fine, provided they fit on the pads.

*Technical explanation: Instead of the SRAM voltage dropping to 1/2 of the battery voltage when the button is pressed, it will drop to 93% of the battery voltage, due to the increased ratio between R1 and R5. This gives plenty of headroom for the SRAM to retain data, even older models. Furthermore, changing C8 to 0.01uF along with the resistors will keep the time constants very similar - changing the button release time constant from 0.002 to 0.0027 and the button press time constant from 0.001 to 0.0013.*

OR

**Fix No. 2:**
- Change R5 to 49.9kΩ: https://mou.sr/3Q3NRZO
This is R10 on the multicart board. You may have extras.

*Technical explanation: Instead of the SRAM voltage dropping to 1/2 of the battery voltage when the button is pressed, it will drop to 83% of the battery voltage. This is still plenty of headroom for the SRAM to retain data. But keeping C8 the same will change the time constant for button release to 0.007 instead of 0.002.*

The differences between the two fixes are minor, but if I had to pick a "proper" one I would go with Fix No. 1. That is what I'll be implementing into the BOM going forward. The reason for this is that the time constants will remain nearly unchanged between the new part values and the old part values - with just changing R5, the RC time constant for the rising edge of the button press is slower. I don't believe it is slow enough to cause any issues, the only thing that could cause a problem is if the CPU starts up before the ROM bank switching is done, but the time constant for the CPU power-on reset is 0.016 at the fastest. Experimentally, both ways seem to work.

--- TL;DR ---

If you made an MBC3 or MBC5 multicart board before February 24, 2024:

- Change R5 and R6 to 130kΩ, and C8 to 0.01uF.

OR

- Change R5 to 49.9kΩ.

If you don't, under certain circumstances you may lose save data while pressing the button to change games while the Game Boy is powered off. **The proper part values have been updated in the BOM as of February 24, 2024.**

Closed 2024-02-24.

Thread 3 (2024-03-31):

mbc3/mbc5

Tom-Neverwinter, 2024-03-31:
where does one even get an mbc3/5 in this day and age?

plc replacements like funnyplaying?

MouseBiteLabs, 2024-03-31:
An original cartridge

On Sun, Mar 31, 2024, 1:30 PM Tom-Neverwinter ***@***.***>
wrote:

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

Closed 2024-03-31.

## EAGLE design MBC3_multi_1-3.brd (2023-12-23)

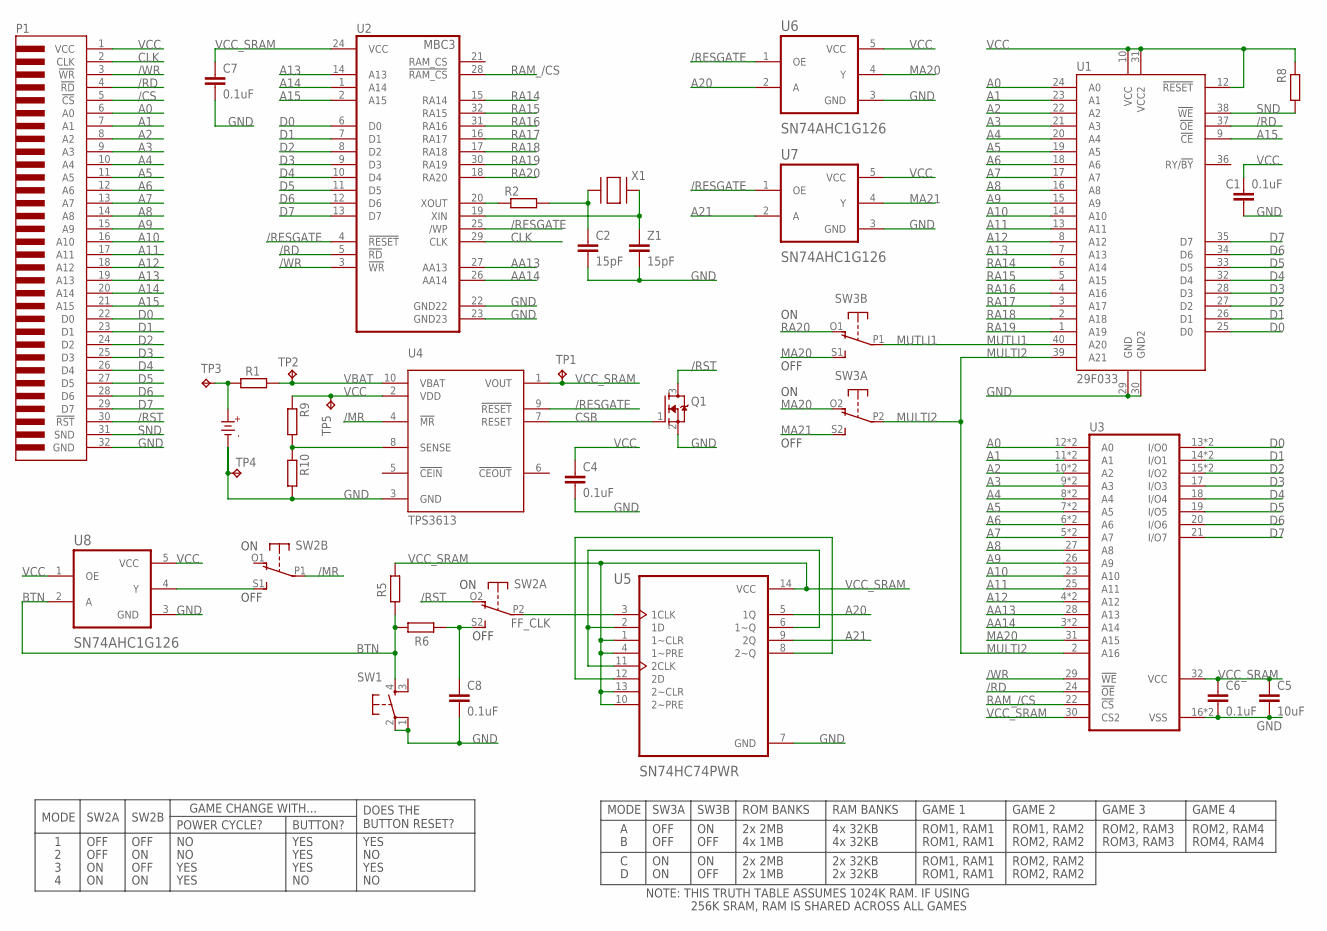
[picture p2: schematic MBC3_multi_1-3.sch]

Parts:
C1, C4, C6, C7, C8: 0.1uF; C0603
C2: 15pF; C0603
C5: 10uF; C0603
P1: GBC_CARTTAB; GBC_CART_TABBED
Q1: 2N7002; SOT23
R1, R2, R5, R6, R8, R9, R10: RR0603; R0603
SW1: SPST_TACT-KMR2; KMR2
SW2, SW3: SPDT-2S; CAS-D20A
TP1, TP2, TP3, TP4, TP5: TPB1,27; B1,27
U1: 29F033; TSOP-40
U2: MBC3; QFP-32
U3: 1008_62256_SRAM; SOP-32L
U4: TPS3613; MSOP-10
U5: SN74HC74PWR; SOP65P640X120-14N
U6, U7, U8: SN74AHC1G126; SC70
U$7: CR2025
X1: XTAL-3.2X1.5; XTAL3215
Z1: 15pF; C0603

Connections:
/CS: P1.5 (!CS)
/MR: SW2.P1, U4.4 (!MR)
/RD: P1.4 (!RD), U1.37 (!OE), U2.5 (!RD), U3.24 (!OE)
/RESGATE: U2.4 (!RESET), U2.25 (/WP), U4.9 (!RESET), U6.1 (OE), U7.1 (OE)
/RST: P1.30 (!RST), Q1.3 (D), SW2.O2 (O)
/WR: P1.3 (!WR), U2.3 (!WR), U3.29 (!WE)
A0: P1.6 (A0), U1.24 (A0), U3.12 (A0), U3.L12 (A0)
A1: P1.7 (A1), U1.23 (A1), U3.11 (A1), U3.L11 (A1)
A2: P1.8 (A2), U1.22 (A2), U3.10 (A2), U3.L10 (A2)
A3: P1.9 (A3), U1.21 (A3), U3.9 (A3), U3.L9 (A3)
A4: P1.10 (A4), U1.20 (A4), U3.8 (A4), U3.L8 (A4)
A5: P1.11 (A5), U1.19 (A5), U3.7 (A5), U3.L7 (A5)
A6: P1.12 (A6), U1.18 (A6), U3.6 (A6), U3.L6 (A6)
A7: P1.13 (A7), U1.17 (A7), U3.5 (A7), U3.L5 (A7)
A8: P1.14 (A8), U1.16 (A8), U3.27 (A8)
A9: P1.15 (A9), U1.15 (A9), U3.26 (A9)
A10: P1.16 (A10), U1.14 (A10), U3.23 (A10)
A11: P1.17 (A11), U1.13 (A11), U3.25 (A11)
A12: P1.18 (A12), U1.8 (A12), U3.4 (A12), U3.L4 (A12)
A13: P1.19 (A13), U1.7 (A13), U2.14 (A13)
A14: P1.20 (A14), U2.1 (A14)
A15: P1.21 (A15), U1.9 (!CE), U2.2 (A15)
A20: U5.5 (1Q), U6.2 (A)
A21: U5.9 (2Q), U7.2 (A)
AA13: U2.27 (AA13), U3.28 (A13)
AA14: U2.26 (AA14), U3.3 (A14), U3.L3 (A14)
BTN: R5.2, R6.1, SW1.4 (S), U8.2 (A)
CLK: P1.2 (CLK), U2.29 (CLK)
CSB: Q1.1 (G), U4.7 (RESET)
D0: P1.22 (D0), U1.25 (D0), U2.6 (D0), U3.13 (I/O0), U3.L13 (I/O0)
D1: P1.23 (D1), U1.26 (D1), U2.7 (D1), U3.14 (I/O1), U3.L14 (I/O1)
D2: P1.24 (D2), U1.27 (D2), U2.8 (D2), U3.15 (I/O2), U3.L15 (I/O2)
D3: P1.25 (D3), U1.28 (D3), U2.9 (D3), U3.17 (I/O3)
D4: P1.26 (D4), U1.32 (D4), U2.10 (D4), U3.18 (I/O4)
D5: P1.27 (D5), U1.33 (D5), U2.11 (D5), U3.19 (I/O5)
D6: P1.28 (D6), U1.34 (D6), U2.12 (D6), U3.20 (I/O6)
D7: P1.29 (D7), U1.35 (D7), U2.13 (D7), U3.21 (I/O7)
FF_CLK: SW2.P2, U5.3 (1CLK)
GND: C1.2, C2.2, C4.2, C5.2, C6.2, C7.2, C8.2, P1.32 (GND), Q1.2 (S), R10.2, SW1.1, SW1.2, TP4.TP, U1.29 (GND), U1.30 (GND2), U2.22 (GND22), U2.23 (GND23), U3.16 (VSS), U3.L16 (VSS), U4.3 (GND), U5.7 (GND), U6.3 (GND), U7.3 (GND), U8.3 (GND), U$7.-, Z1.2
MA20: SW3.O2 (O), SW3.S1 (S), U3.31 (A15), U6.4 (Y)
MA21: SW3.S2 (S), U7.4 (Y)
MULTI2: SW3.P2, U1.39 (A21), U3.2 (A16)
MUTLI1: SW3.P1, U1.40 (A20)
unnamed: C8.1, R6.2, SW2.S2 (S)
unnamed: SW2.S1 (S), U8.4 (Y)
unnamed: R1.2, TP3.TP, U$7.+
unnamed: U5.2 (1D), U5.6 (1~Q), U5.11 (2CLK)
unnamed: R2.1, U2.20 (XOUT)
unnamed: C2.1, R2.2, X1.P$2
unnamed: U2.19 (XIN), X1.P$1, Z1.1
unnamed: R9.2, R10.1, U4.8 (SENSE)
unnamed: U5.8 (2~Q), U5.12 (2D)
RA14: U1.6 (A14), U2.15 (RA14)
RA15: U1.5 (A15), U2.32 (RA15)
RA16: U1.4 (A16), U2.31 (RA16)
RA17: U1.3 (A17), U2.16 (RA17)
RA18: U1.2 (A18), U2.17 (RA18)
RA19: U1.1 (A19), U2.30 (RA19)
RA20: SW3.O1 (O), U2.18 (RA20)
RAM_/CS: U2.28 (!RAM_CS), U3.22 (!CS)
SND: P1.31 (SND), R8.2, U1.38 (!WE)
VBAT: R1.1, TP2.TP, U4.10 (VBAT)
VCC: C1.1, C4.1, P1.1 (VCC), R8.1, R9.1, TP5.TP, U1.10 (VCC), U1.12 (!RESET), U1.31 (VCC2), U4.2 (VDD), U6.5 (VCC), U7.5 (VCC), U8.1 (OE), U8.5 (VCC)
VCC_SRAM: C5.1, C6.1, C7.1, R5.1, TP1.TP, U2.24 (VCC), U3.30 (CS2), U3.32 (VCC), U4.1 (VOUT), U5.1 (1~CLR), U5.4 (1~PRE), U5.10 (2~PRE), U5.13 (2~CLR), U5.14 (VCC)

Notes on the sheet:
OFF
SW3A
SW3B
ROM BANKS
RAM BANKS
4x 1MB
4x 32KB
2x 1MB
2x 2MB
2x 32KB
GAME 1
GAME 2
GAME 3
GAME 4
ROM1, RAM1
ROM2, RAM2
ROM3, RAM3
ROM4, RAM4
ROM1, RAM2
ROM2, RAM3
ROM2, RAM4
NOTE: THIS TRUTH TABLE ASSUMES 1024K RAM. IF USING
256K SRAM, RAM IS SHARED ACROSS ALL GAMES
MODE
SW2A
SW2B
POWER CYCLE?
DOES THE BUTTON RESET?
YES
BUTTON?
GAME CHANGE WITH...

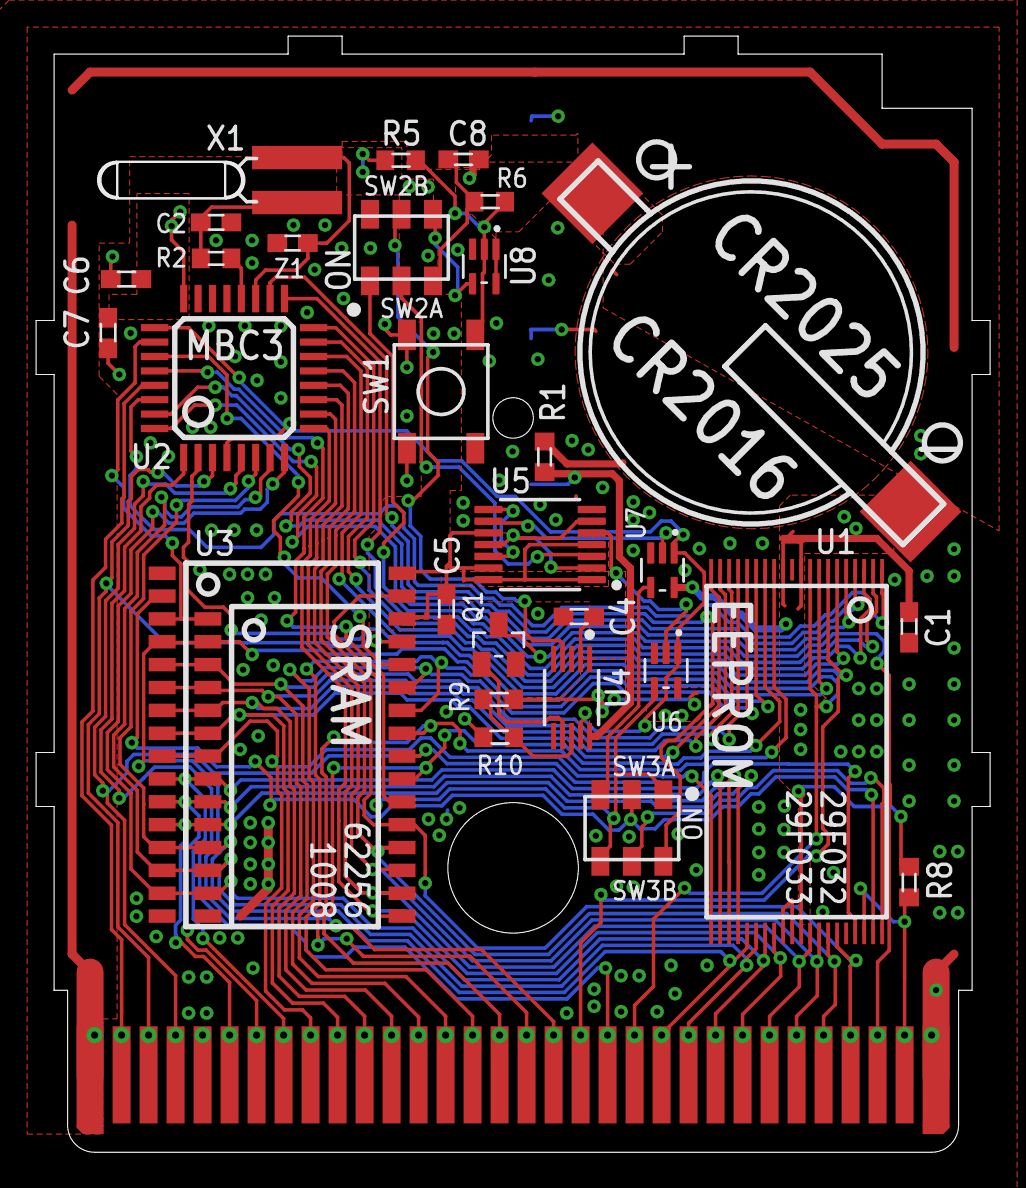
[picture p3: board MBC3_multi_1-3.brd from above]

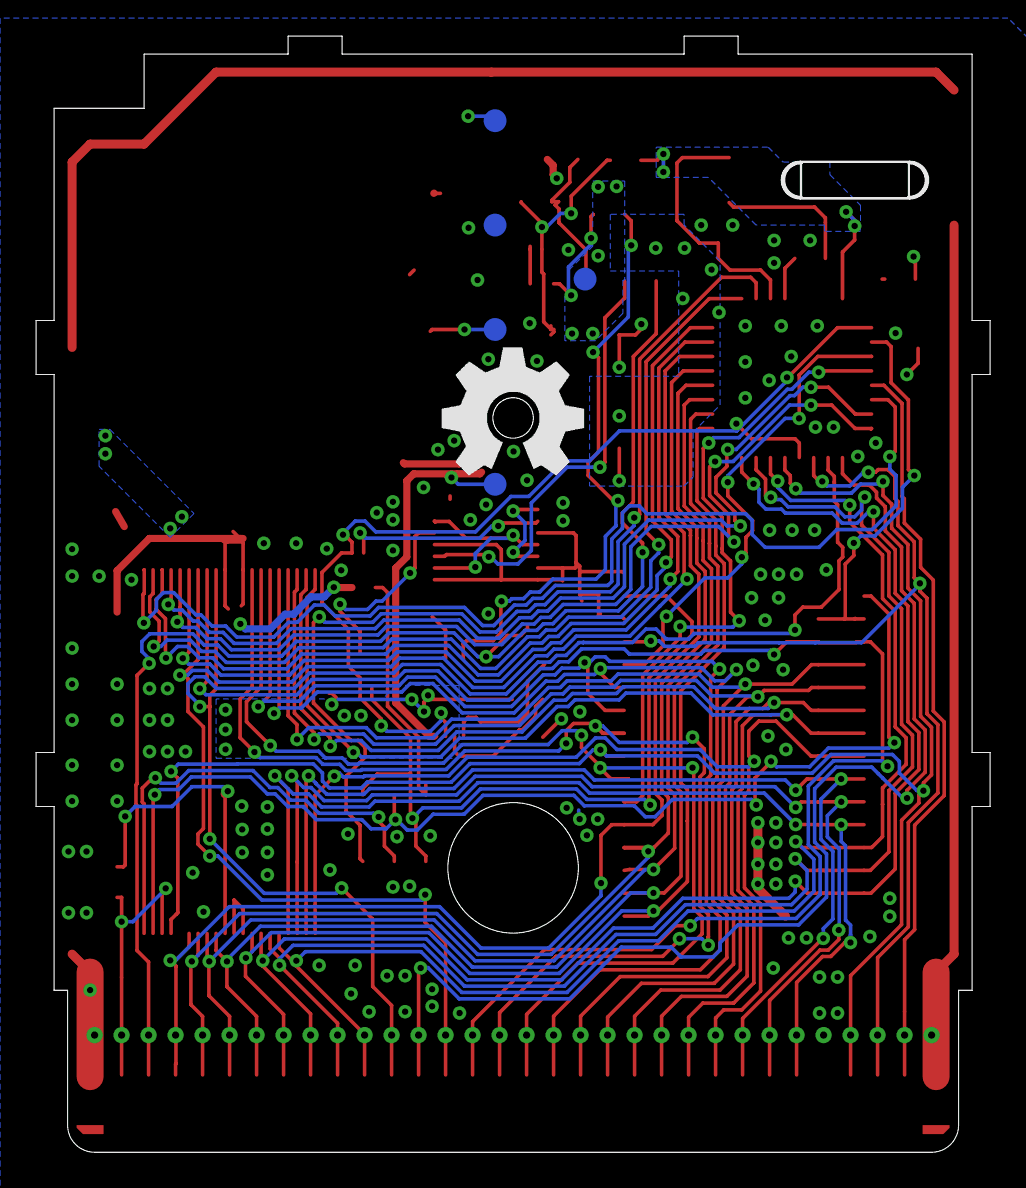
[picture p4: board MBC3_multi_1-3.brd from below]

Board: 2 copper layers, 53.0 x 62.0 mm, 35 parts (5 on the bottom side), 63 nets.
